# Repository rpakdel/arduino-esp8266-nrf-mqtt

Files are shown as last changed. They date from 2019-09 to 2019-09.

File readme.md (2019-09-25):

# ESP8266 connected to sensors via NRF24L01 publishing via MQTT

* RobotDyn ESP8266-PRO connected to NRF24L01 listening to three pipes.
* ESP8266-PRO publishes sensor values to Mosquitto server.

* Three remote sensors connected to Arduino Pro Mini send values to ESP8266-PRO via NRF24L01.
* Sensors go to sleep periodically and put the radio to sleep as well.
* Sensor ID 0 is connected to a button and runs on 3 AA batteries. 
 * Interrupt routine wakes up Arduino and NRF24L01 radio when button pressed.
 * Arduino and radio go back to sleep after sending message.

* Node-RED on Raspberry Pi decides what to do with sensor messages.
* Sensor ID 0 messages toggle IKEA Tradfri wireles outlet via CC2531 Zigbee module connected to Raspberry Pi.

## Pictures

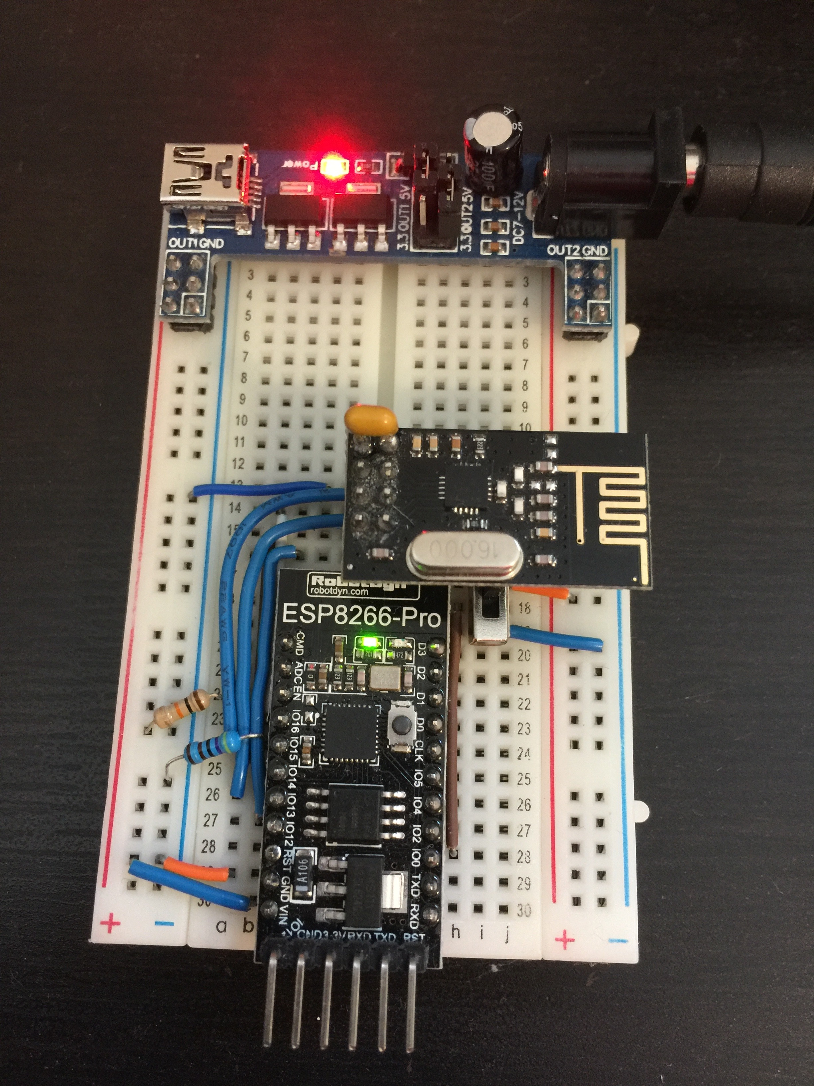
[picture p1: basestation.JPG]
Basestation with ESP8266 MQTT client and NRF24L01 receiver.

Basestation with ESP8266 MQTT client and NRF24L01 receiver.

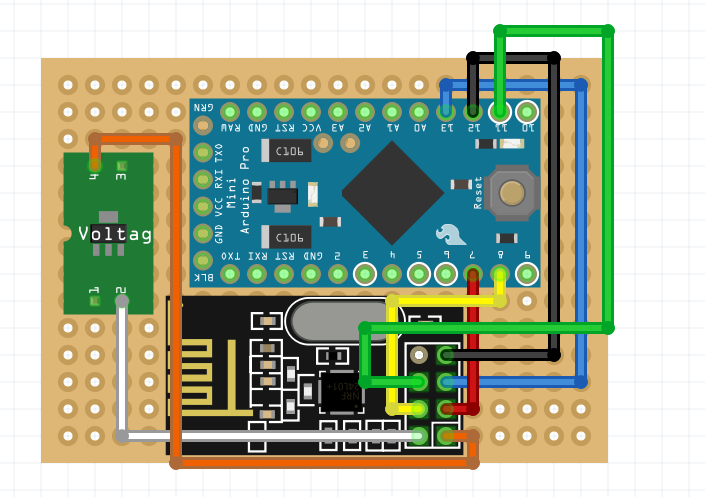
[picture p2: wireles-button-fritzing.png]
Wireless button PCB design in Fritzing.

<br/>
Wireless button PCB design in Fritzing.

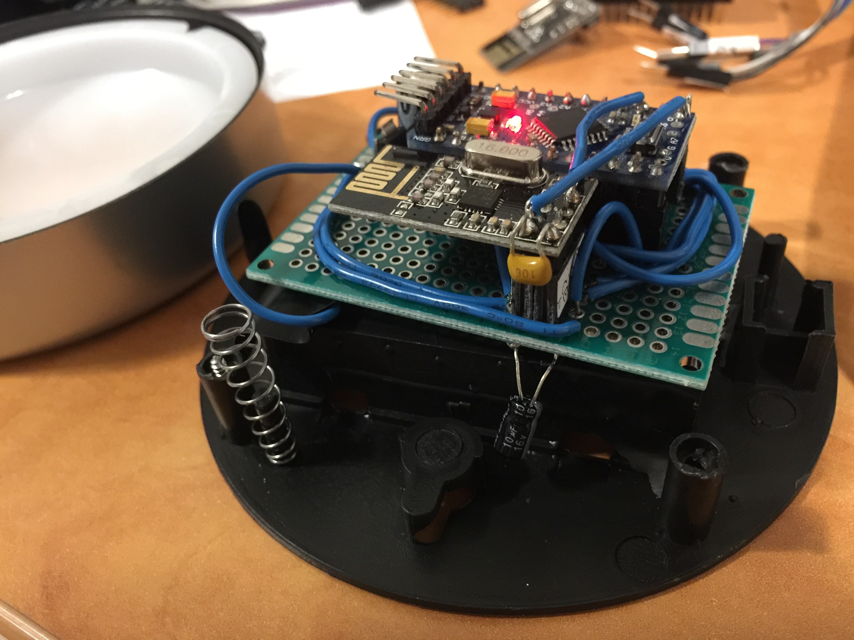
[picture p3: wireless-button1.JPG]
Dollar store LED light repurposed.

Dollar store LED light repurposed.

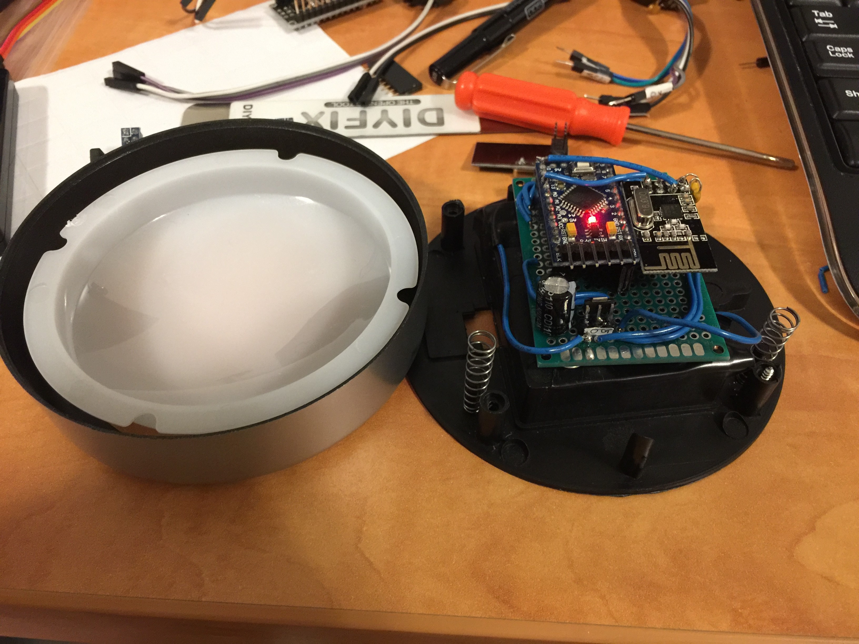
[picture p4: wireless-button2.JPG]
Another view of the Arduino and NRF24L01.

Another view of the Arduino and NRF24L01. Had many connection issues with the female headers. Also many issues with power stability which required 2x 0.1uF capacitors.

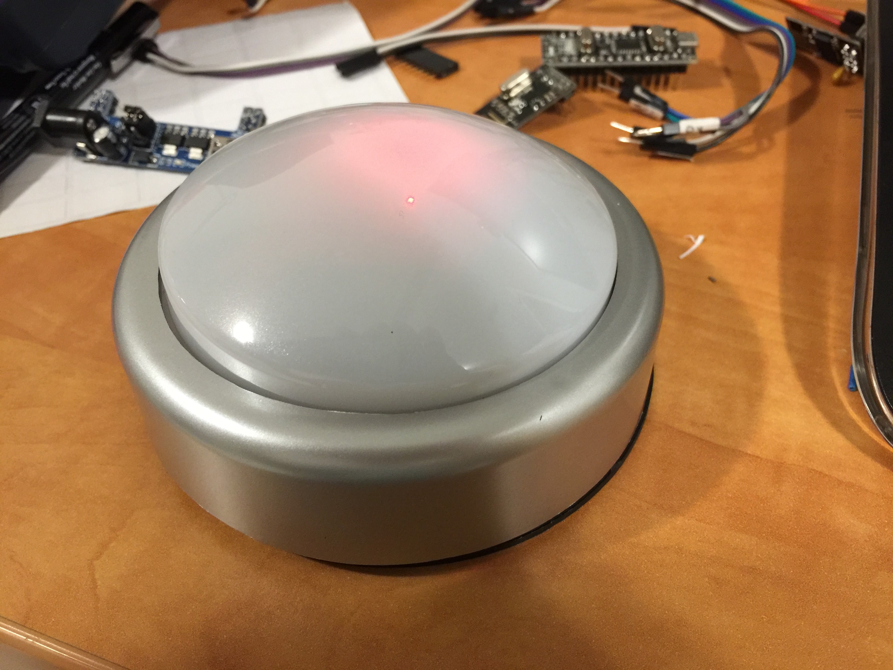
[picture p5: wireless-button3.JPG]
Completed project. The red LED light is covered with black tape.

Completed project. The red power LED light is covered with black tape. 

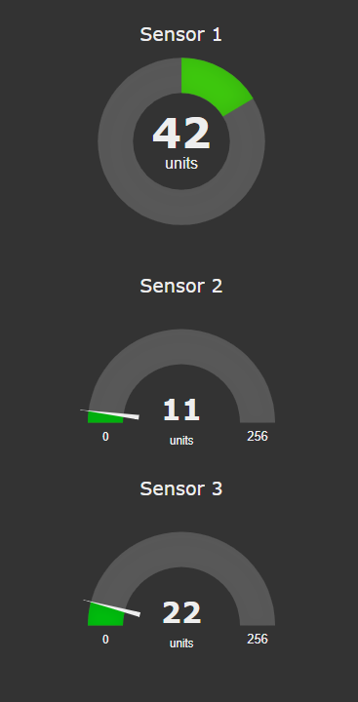
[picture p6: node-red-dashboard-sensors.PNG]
Node-RED Dashboard showing the sensor values

<br/>
Node-RED Dashboard showing the sensor values (currently just counting to 0 to 255).

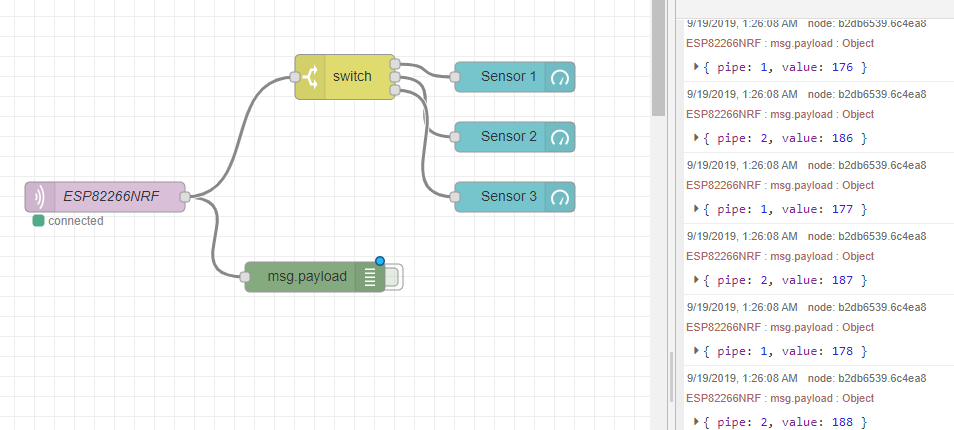
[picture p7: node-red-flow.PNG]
Node-RED flow

Node-RED flow for the sensors.

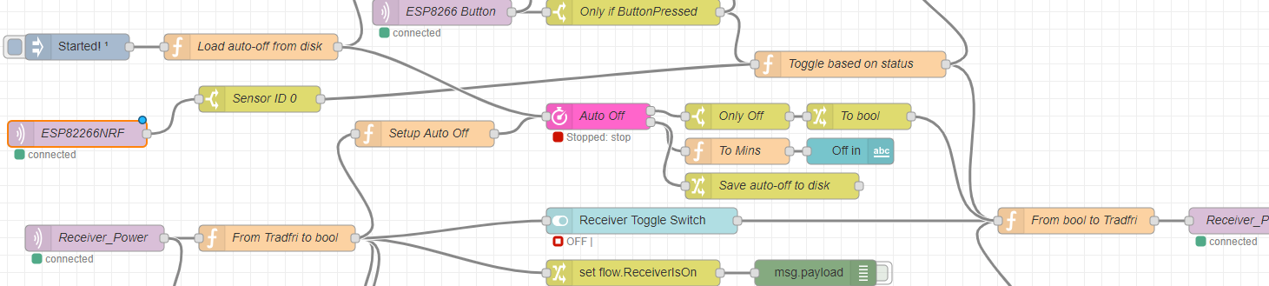
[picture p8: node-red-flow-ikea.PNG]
Node-RED flow IKEA

Node-RED flow for turning IKEA Tradfri outlet on/off with auto-off feature.

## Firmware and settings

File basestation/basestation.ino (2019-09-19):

/* 
* RobotDyn ESP8266-PRO with I2C and SPI connections
*/

#include <SPI.h>
#include <nRF24L01.h>
#include <RF24.h>

#include <ESP8266WiFi.h>
#include <PubSubClient.h>

#include "myssid.h"
#include "esp8266-pro-pins.h"

// GPIO15 -> GND with 4.7k resistor
// EN -> 3.3v with 10k resistor
// GPIO0 -> GND to flash/program
// GPIO0 -> 3.3v to run normally

// OLED SDA -> GPIO4
// OLED SCK -> GPIO5
//SSD1306AsciiWire oled;

// RF MISO -> GPIO12
// RF MOSI -> GPIO13
// RF SCK  -> GPIO14
#define CSPIN GPIO15 // to GND with 4.7k resistor
#define CEPIN GPIO16

RF24 radio(CEPIN, CSPIN);
#define NUM_SENDERS 3
byte addresses[NUM_SENDERS][6] = { 
	"1MQTT",
	"2MQTT",
	"3MQTT",
};

#define MQTT_SERVER "192.168.1.29"
#define MQTT_TOPIC "ESP82266NRF"

WiFiClient espClient;
PubSubClient pubsubClient(espClient);

void setupWiFi()
{
    // Connect to WiFi network
    Serial.print(F("Connecting to "));
    Serial.println(MYSSID);

    WiFi.begin(MYSSID, MYPASSWORD);

    while (WiFi.status() != WL_CONNECTED) 
	{
        delay(500);
        Serial.print(F("."));
    }
    Serial.println();
    Serial.print(F("WiFi connected: "));
    Serial.println(WiFi.localIP());
}

void setupRadio()
{
    radio.begin();
    radio.setPALevel(RF24_PA_MIN);
    radio.setAutoAck(1);
    radio.setRetries(15, 15);
	for (int i = 0; i < NUM_SENDERS; i++)
	{
		radio.openReadingPipe(i, addresses[i]);
	}
    radio.startListening();
}

void checkRadio()
{
	uint8_t pipeNum = 0;
    if (radio.available(&pipeNum))
    {
        uint8_t buffer;
        radio.read((uint8_t*)&buffer, sizeof(uint8_t));
		//Serial.print(pipeNum);
        //Serial.print(F(" Receiver: "));
        //Serial.println(buffer);

		String payload = "{ ";
		payload += "\"pipe\" : " + String(pipeNum) + ", ";
		payload += "\"value\" : " + String(buffer);
		payload += " }";

		Serial.println(payload);
		pubsubClient.publish(MQTT_TOPIC, payload.c_str());
    }
}

void reconnectToMQTTServer() 
{
	while (!pubsubClient.connected()) 
	{
		String clientId = "ESP8266Client-";
		clientId += String(random(0xffff), HEX);
		// Attempt to connect
		if (pubsubClient.connect(clientId.c_str()))
		{
			// Once connected, publish an announcement...
			pubsubClient.publish(MQTT_TOPIC, "online");
		}
		else 
		{
			Serial.print("failed, rc=");
			Serial.print(pubsubClient.state());
			Serial.println(" try again in 5 seconds");
			// Wait 5 seconds before retrying
			delay(5000);
		}
	}
}

void mqttCallback(char* topic, byte* payload, unsigned int length) 
{
	Serial.print("Message arrived [");
	Serial.print(topic);
	Serial.print("] ");
	for (int i = 0; i < length; i++) 
	{
		Serial.print((char)payload[i]);
	}
	Serial.println();
}

void setupMQTT()
{
	pubsubClient.setServer(MQTT_SERVER, 1883);
	pubsubClient.setCallback(mqttCallback);
}

void setup()
{
    Serial.begin(115200);
    setupRadio();
    setupWiFi();
	setupMQTT();
}

void loop()
{
	if (!pubsubClient.connected()) 
	{
		reconnectToMQTTServer();
	}

	pubsubClient.loop();
    checkRadio();
}

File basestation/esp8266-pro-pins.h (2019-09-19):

#pragma once

// ESP8266-PRO uses ESP8266EX chip
// http://www.liot.io/hardware/planning/


#define GPIO0 0
#define GPIO1 1
#define GPIO2 2
#define GPIO3 3
#define GPIO4 4
#define GPIO5 5
#define GPIO6 6
#define GPIO7 7
#define GPIO8 8
#define GPIO9 9
#define GPIO10 10
#define GPIO11 11
#define GPIO13 12
#define GPIO13 13
#define GPIO14 14
#define GPIO15 15
#define GPIO16 16

#define RX0 GPIO3
#define TX0 GPIO1

#define RX1 GPIO8
#define TX1 GPIO2

#define SDIO_CLK GPIO6
#define SDIO_D0 GPIO7
#define SDIO_D1 GPIO8
#define SDIO_D2 GPIO9
#define SDIO_D3 GPIO10
#define SDIO_CMD GPIO11

#define HSPI_CLK GPIO14
#define HSPI_MISO GPIO12
#define HSPI_MOSI GPIO13
#define HSPI_CS GPIO15

#define SPI_CLK GPIO6
#define SPI_MISO GPIO7
#define SPI_MOSI GPIO8
#define SPI_CS GPIO11

#define I2C_SCL GPIO14
#define I2C_SDA GPIO2

#define XPD_DCDC GPIO16

#define WIFI_LED GPIO0
#define LINK_LED GPIO12

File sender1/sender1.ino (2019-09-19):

 /*
* Basic sender based on RF24 example
*/

#include <LowPower.h>
#include <RF24_config.h>
#include <printf.h>
#include <SPI.h>
#include <nRF24L01.h>
#include <RF24.h>
#include <LowPower.h>

#define NUM_SENDERS 3
#define SENDER 0

#define CEPIN 9
#define CSPIN 10

RF24 radio(CEPIN, CSPIN);

byte addresses[NUM_SENDERS][6] = {
	"1MQTT",
	"2MQTT",
	"3MQTT",
};

void setup() 
{    
	pinMode(2, INPUT_PULLUP);
    Serial.begin(115200);
    Serial.print(F("SENDER"));
    Serial.println(SENDER);

	radio.begin();
    radio.setRetries(15, 15);
    radio.setPALevel(RF24_PA_MIN);
    radio.openWritingPipe(addresses[SENDER]);
	radio.stopListening();
	radio.powerDown();
}

uint8_t count = 0;
void sendValue()
{
	Serial.print(F("Sending "));
	Serial.print(count);
	radio.powerUp();
	if (!radio.write((uint8_t*)&count, sizeof(uint8_t)))
	{
		Serial.println(F("...no ack"));

	}
	else
	{
		Serial.println(F("...ack"));
	}
	radio.powerDown();
	count++;
}

void wakeup()
{
	noInterrupts();
	sendValue();
	interrupts();
}

void loop()
{
	Serial.println("attach, sleep");
	attachInterrupt(digitalPinToInterrupt(2), wakeup, FALLING);
	LowPower.powerDown(SLEEP_FOREVER, ADC_OFF, BOD_OFF);
	delay(100);
	Serial.println("wakeup, detach");
	detachInterrupt(0);
}
